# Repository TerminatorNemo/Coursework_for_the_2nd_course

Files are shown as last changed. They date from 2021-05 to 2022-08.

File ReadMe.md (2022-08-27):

# This is a folder with course work on analog electronics for the 2nd year

[Link to the video with the defense of the coursework](https://www.youtube.com/watch?v=7gKAiLStUtM&t=1s)

[Report for term paper](https://github.com/TerminatorNemo/Coursework_for_the_2nd_course/blob/main/Report%20for%20term%20paper.pdf)

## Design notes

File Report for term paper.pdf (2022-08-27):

НАЦІОНАЛЬНИЙ ТЕХНІЧНИЙ УНІВЕРСИТЕТ УКРАЇНИ «КИЇВСЬКИЙ ПОЛІТЕХНІЧНИЙ ІНСТИТУТ ІМЕНІ ІГОРЯ СІКОРСЬКОГО» Кафедра конструювання електронно-обчислювальної апаратури

КУРСОВА РОБОТА

з дисципліни ______Електронна компонентна база радіоелектронної апаратури______ на тему:___________ Підвищуючий DC-DC перетворювач на 555 таймері___________ __________________________________________________________________________

Студента 2 курсу групи ДК-92
Напряму підготовки: Телекоммунікації та радіотехніка
_______________Загреба А.Я._____________
(прізвище та ініціали)
Керівник:
________доцент, к.т.н. Короткий Є.В._______
(посада, вчене звання, науковий ступінь, прізвище та ініціали)
Національна оцінка: _____________________ Кількість балів: ______ Оцінка: ECTS ______
Члени комісії: _____________ | ___доцент, к.т.н. Короткий Є.В.___
(підпис) | (вчене звання, науковий ступінь, прізвище та ініціали)
_____________ | _________________________________
(підпис) | (вчене звання, науковий ступінь, прізвище та ініціали)

Київ - 2021 рік

ЗМІСТ

Розділ 2. Визначення характеристик, необхідних для вибору компонентів схеми ..... 9

ПЕРЕЛІК УМОВНИХ СКОРОЧЕНЬ

ШІМ-Широтно-імпульсна модуляція ЕРС- Електрорушійна сила
BOM- Bill Of Materials
УГО - Умовно графічне позначення КР – Курсова робота
NTC – Negative temperature coefficient DC – Direct current

ВСТУП

Темою КР було обрано підвищуючий DC-DC перетворювач на 555 таймері, який може перетворювати напругу 9 В у більш високу – 12 В. За основу була взята схема з сайту [1], але довелося замінити індуктивність та зворотний зв’язок, щоб на виході будо 12 В замість 19 В.

Метою цієї роботи є: аналіз та виправлення оригінальної схеми, замір струмів та напруг на компонентах, вибір компонентної бази, створення 3D моделі котушки індуктивності, створення бібліотеки та трасировка плати у Altium Designer.
В першому розділі буде проаналізовано роботу схеми та перероблено її на вхідну напругу 9 В та вихідну 12 В. Замість вхідної 12 В та вихідної 19 В.
В другому розділі буде виміряно напруги та струми на компонентах та занесено їх до таблиці.
В третьому розділі буде обрано потрібні компоненти.
В четвертому розділі буде розроблено 3D модель.
В п’ятому розділі буде розроблено бібліотеку для котушки та трасовано плату у Altium Designer.

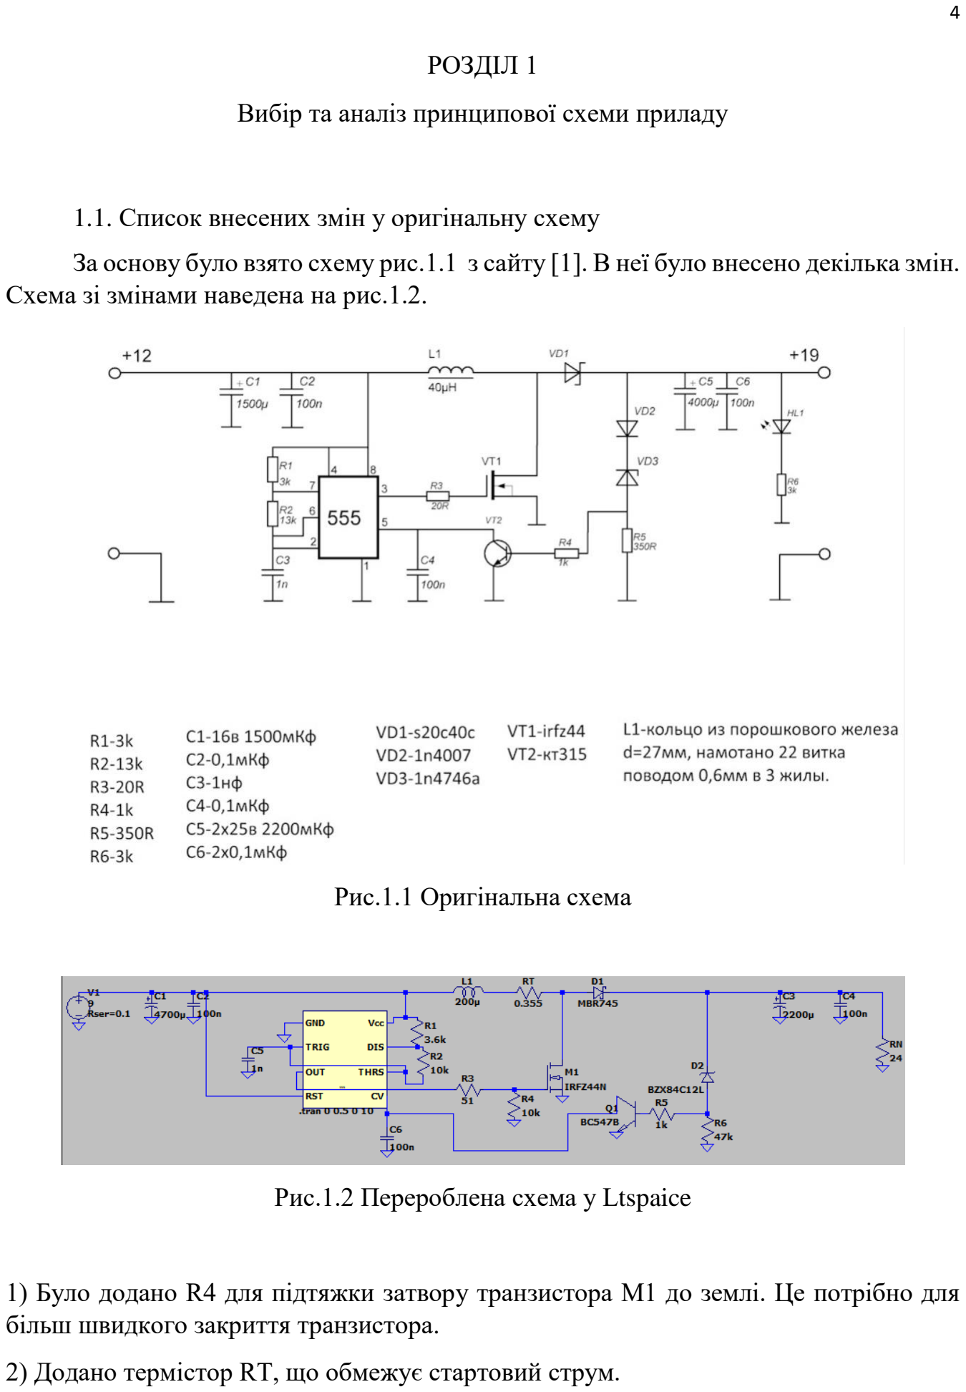
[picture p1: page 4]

РОЗДІЛ 1

Вибір та аналіз принципової схеми приладу

1.1. Список внесених змін у оригінальну схему

За основу було взято схему рис.1.1 з сайту [1]. В неї було внесено декілька змін. Схема зі змінами наведена на рис.1.2.

Рис.1.1 Оригінальна схема

Рис.1.2 Перероблена схема у Ltspaice

1) Було додано R4 для підтяжки затвору транзистора M1 до землі. Це потрібно для більш швидкого закриття транзистора.
2) Додано термістор RT, що обмежує стартовий струм.

3) Змінено зворотний зв’язок, щоб вихідна напруга була 12 В. Для цього було замінено стабілітрон на 12-вольтний та прибрано VD2, оскільки він став не потрібен (цей діод слугував для підвищення вихідної напруги на 0,7 В).
4) Резистори R1 та R2 були замінені на більш ходові. Через це частота ШІМ трохи змінилася, але це не критично (було 50 КГц, стало 63 КГц).
5) Опір резистора R3 було змінено, бо 555 таймер може видати 225 mA, напруга на третьому виводі сягає до 9 В, з резистором 20 Ом струм був би

9
20

= 0,45 А = 450 мА > 225 мА.

А з опором 51 Ом струм буде

9
51

= 0,18 А = 180 мА,

це 80% від максимального струму.

6) Було замінено діод VD1 (D1) на більш потужний аналог, бо не було можливості придбати той, що було використано в оригнальній схемі.
7) Було замінено конденсатори С1 та С3. Причиною заміни С1 стали великі пульсації на вході. С3 було замінено для більш швидкого виходу на робочий режим.
1.2. Аналіз роботи схеми
1.2.1. Вхідні конденсатори

Вхідні конденсатори С1 та С2 згладжують пульсації на вході схеми. А також дозволяють короткочасно отримувати великий струм. Короткочасний великий струм потрібен для пропускання великого струму через L1 при відкритому М1. Таким чином при закриванні М1 на котушці буде велика зміна струму за малий час. А це є умовою виникнення великого ЕРС самоіндукції.

Після чого 555 таймер генерує ШІМ сигнал з частотою 63 КГц на третьому виводі. Частота та скважність ШІМ задаються резисторами R1, R2 та конденсатором С5.

1.2.2. Генерація ШІМ таймером 555

Конденсатор С5 заряджається через резистори R1 та R2 (рис.1.2.2.1).

Поки напруга на С5 менше 1/3 напруги живлення на компараторі R (що підключений до інвертуючого контакту тригера) логічний сигнал 0, на виході компаратора S (що підключений до неінвертуючого контакту тригера) сигнал 1. Отже на інвертуючому виході тригера 0. В наслідок чого на виході схеми напруга живлення (бо після тригера стоїть інвертор).

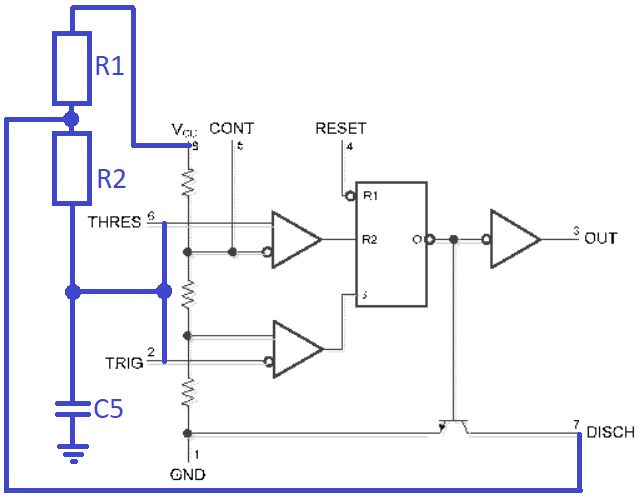
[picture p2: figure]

Рис.1.2.2.1 Схема 555 таймеру:

1) чорним представлена спрощена внутрішня схема 555 таймеру;
2) синім – його обв’язка у схемі.

Коли напруга на С5 більше 1/3 напруги живлення, але менше 2/3 напруги живлення, на виході обох компараторів 0, на виході тригера все ще 0. На виході схеми буде напруга живлення.

Коли напруга на С5 більше 2/3 напруги живлення, у компаратора R на виході 1, на виході компаратора S – 0, одже на виході тригера 1. Через це відкривається вбудований транзистор, конденсатор починає розряджатися через резистор R2. На виході схеми – 0 В.

Коли напруга на С5 більше 1/3 напруги живлення, але менше 2/3 напруги живлення, на виході обох компораторів 0, на виході тригера все ще 1. На виході схеми все ще 0 В.

Коли напруга на С5 стане менше 1/3 напруги живлення, на компараторі R логічний сигнал 0, а на виході компаратора S сигнал 1. Одже, на виході тригера 0. Транзистор закривається, цикл повторюється. На виході схеми напруга живлення.

Якщо вихід CONT (5 контакт) підтягнути до землі, опорна напруга компораторів зменшиться, скважність сигналу – зменшиться, частота – виросте.

1.2.3. Для чого потрібен ШІМ сигнал в цій схемі

ШІМ керує транзистором М1, коли транзистор відкрито – через індуктивність L1 тече струм.

В момент, коли транзистор закривається, на котушці індуктивності з’являється ЕРС самоіндукції, через різьке припинення протікання струму. (Чим більше зміна струму за менший час, тим більше ЕРС самоіндукції). ЕРС самоіндукції завжди направлено так, що воно протидіє зміні струму.

В нашому випадку, напрям ЕРС самоіндукції направлено вздовж стрілки (рис.1.2.2.2).

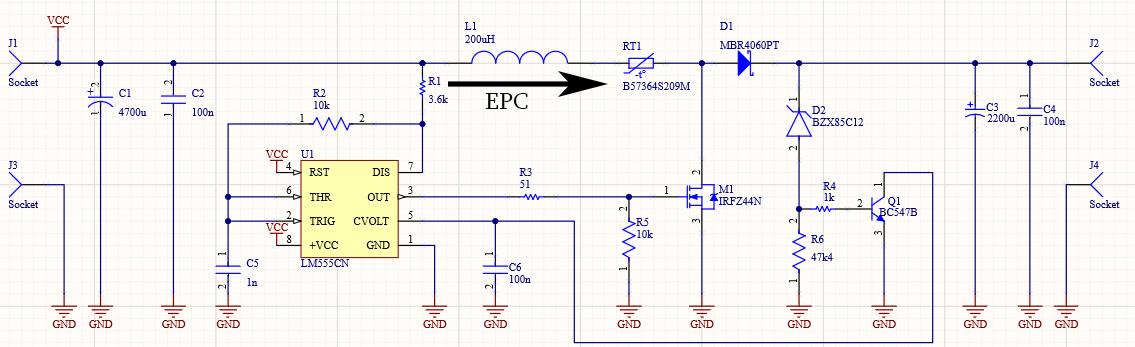
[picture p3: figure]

Рис.1.2.3.2 Схема з позначенням напрямку ЕРС.

Коли ЕРС перевищує напругу на вихідних конденсаторах на 0,7 В, діод D1 відкривається, вихідні конденсатори заряджаються.

1.2.4. Зворотний зв’язок

Якщо напруга на вихідних конденсаторах перевищує 12 В, стабілітрон D2 пробивається. Через нього починає текти струм, що відкривае транзистор Q1, який підтягує п’ятий вивід 555 таймеру до землі. Чим більший струм пропускає через себе стабілітрон, тим більше відкривається транзистор, тим сильніше він підтягує п’ятий вивід до землі, тим менше скважність ШІМ. Одже менше магнітної енергії накопичує котушка, через це менше ЕРС самоіндукції. Скважність може зменшуватись до повного відключення генерації, в такому випадку навантаження живиться від вихідних конденсаторів.

Коли напруга падає нижче 12 В, стабілітрон D2 закривається, транзистор Q1, закривається. В наслідок чого перестає підтягувати п’ятий вивід 555 таймеру до землі, таймер збільшує скважність ШІМ. І так по колу.

1.2.5. NTC термістор

NTC термістор потрібен, щоб при підключенні схеми вона не потребувала великого струму, з часом він розігрівається, його опір падає, і термістор майже не впливає на роботу схеми.

Термістор стоїть саме в цьому місті, оскільки, поки він не розігрівся, він визиває просадки напруги (оскільки обмежує струм). Якби він стояв до 555, могли б бути збої в роботі. А до чи після котушки – не суттєво, бо тут послідовне підключення.

1.3. Розрахунок котушки індуктивності

Тепер, оскільки було змінено вихідну та вхідну напруги, перерахуємо значення індуктивності котушки L1.

Uin=9В (напруга входу),

Uout=12В (напруга виходу),

Iout=0,5А (струм виходу),

f=63kГц=63 000Гц (частота ШІМ).

Lmin =

0.063∗Uout
Iout∗f

=

0.063∗12
0.5∗63000
= 0.000024Г=24mkГ. | (1.1)

Lmin =

0.25∗Uout
ImaxVT∗f

=

0.25∗12
48∗63000
= 0.000017Г=17mkГ. | (1.2)

Формули (1.1) і (1.2) було взято з [2], там це формули (10.16) і (10.17) відповідно.

Для надійної роботи краще взяти разів в 10 більше, отже візьмемо 200мкГ.

РОЗДІЛ 2

Визначення характеристик, необхідних для вибору компонентів схеми

Струми та напруги були виміряні у LTspaice. Виміри були проведені до розігріву термістора та після розігріву (замість термістора було використано резистор з еквівалентним опором). Всі значення було занесено у таблицю 2.1.

Потужність резисторів визначалася за формулою P=UI.

Таблиця 2.1

Струми та напруги на компонентах схеми

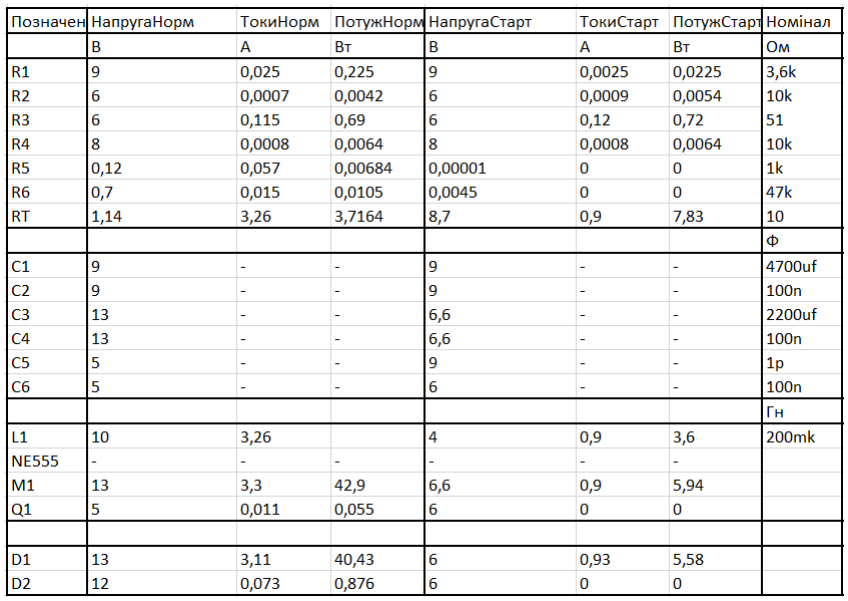
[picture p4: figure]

Норм – після розігріву термістора.

Старт – до розігріву термістора.

Посилання на схему, створену у Altium Designer [4]

РОЗДІЛ 3

Вибір елементної бази

В якості резистора R1 було обрано ERJ-P14J362U, оскільки його потужність 0,5 Вт, це більше за 0,24 Вт. (Якщо взяти резистор з потужністю 0,25 Вт, то буде замалий запас.) Номінал відповідає потрібному. Оскільки в схемі присутній зворотний зв’язок, то можна взяти резистор з невеликою точністю, отже 5% достатньо.
В якості резисторів R2, R5 (у LTspaice це R2 та R4) було вибрано RN73C2A10KBTG. Номінал відповідає потрібному. Потужність 0,1 Вт значно більше тої, що виділяється на цих резисторах.
Для R3 було вибрано ERJ-1TNF51R0U, номінал відповідає потрібному. Потужність в 1 Вт перевищує 0,72 Вт на 38,9%. При опорі 51 Ом, струм через нього становить 180 мА, це 80% від максимального струму 555 таймеру. Цей резистор має точність 1%, таким чином струм точно не перевищить 225 мА.
R4 (у LTspaice R5) це | RK73H2ATTE1001F, номінал відповідає, номінальна
потужність значно більше | розсіювальної. Формфактор 0805 дозволяє зібрати схему
вручну.

R6 – CRGP0805F47K. Номінал відповідає потрібному. Потужність більше розсіювальної.

C1 – MALREKA00FG447DG0K. Ємність відповідає потрібній. А напруга – був вибір або 16 В, або 9 В, оскільки напруга на ньому 9 В, то було вибрано 16 В, щоб був запас.

C2, C4, C6 - номінал відповідає, напруга 25 В, це більше 9 В та 12 В. Формфактор 0805, як було написано вище, менше брати не має сенсу.

C3 – 16ZLQ2200MEFC10X25. Номінал відповідає, напруга 16 В більше максимальної 13 В.

C5 – GMC21CG1R0C200NT, номінал відповідає, напруга значно більше максимальної, формфактор 0805. Точність – достатня.

RT1 – B57364S209M. Оскільки його задача обмежити стартовий струм, тут не потрібна велика точність, тому 20% точності достатньо. Він має пропускати не маленький струм (3,26 А), цей термістор розраховано на 12 А. Також можна використати його аналог, MF72-010D20, його максимальний струм 6 А, але цього все одно достатньо.

M1 – IRFZ44N, масксимальна розсіювальна потужність 110 Вт. Він в схемі не буде розсіюати більше 41 Вт, порогова напруга затвора 4 В, 555 таймер видає 9 В (у цій схемі).

Q1 – BC547B було використано в оригінальній схемі, але можна використати його аналог S9014.

U1 – LM555CN, оскільки використання приладу планується тільки у жилому приміщенні, то робоча температура 0–70 ˚С підходить. Напруга живлення 4–16 В, в схемі буде живитися від 9 В.

L1 – зроблена вручну. Діаметр дроту має бути не менше 0,66 мм. Індуктивність (як написано у розділі 1) 200 мкГн.

BOM експортований з Altium Designer (таблиця 3.1) [5].

Таблиця 3.1

BOM з Altium Designer

Comment | Description | Designator | Footprint | LibRef | Quantity
MALREKA00FG4 47DG0K | Cap Alum 4700UF 20% 16V Radial | C1 | FP-ECA-1HM102-MFG | MALREKA00FG 447DG0K | 1
C0805C104K3RA CAUTO | CAP CER 0.1UF 25V X7R 0805 | C2, C4, C6 | FP-C0805C-DN-IPC_A | CMP-2007-01164-2 | 3
16ZLQ2200MEFC 10X25 | Cap Aluminum Lytic 2200uF 16V 20% (10 X 25mm) Radial 5mm 2500mA 5000h 105C | C3 | PNSC-EEUFM1H221-2 | 16ZLQ2200MEF C10X25 | 1
GMC21CG1R0C2 00NT | CAP0805 COG 1PF .25PF 200V | C5 | FP-C0805C-DN-IPC_A | CMP-2007-00243-2 | 1
MBR4060PT | Schottky Diodes & Rectifiers 43 amp Rectifiers Schottky Barrier | D1 | FP-340BZ-MFG | MBR4060PT | 1
BZX85C12 | DIODE ZENER 12V 1W DO41 | D2 | FP-017AH-MFG | CMP-07164-000008-1 | 1

Продовж. табл. 3.1

Socket | Socket | J1, J2, J3, J4 | PIN1 | Socket | 4
IRFZ44N | MOSFET, Power; N-Ch; VDSS 55V; RDS(ON) 17.5 Milliohms; ID 49A; TO-220AB; PD 94W; -55deg | M1 | INF-PG-TO220-3-1 | IRFZ44N | 1
BC547B | Amplifier Transistor, NPN Silicon, 3-Pin TO-92, Bulk Box | Q1 | ONSC-TO-92-3-29-11 | CMP-1048-01467-1 | 1
ERJ-P14J362U | | R1 | RESC3225X70X 50ML20T20 | CMP-2005-03719-1 | 1
RN73C2A10KBT G | SMD Chip Resistor, Thin Film, 10KΩ, 100 V, 0805 [2012 Metric], 100 mW, 0.1%, RN73 Series | R2, R5 | FP-RN732A-IPC_A | CMP-03211-001029-1 | 2
51R 1% 2512(6432) | 51R 1W 1% 2512 (6432 Metric) SMD | R3 | RESC2512(6432) _M | CMP-1018-00364-1 | 1
RK73H2ATTE100 1F | | R4 | RESC2013X60X 30ML20T20 | CMP-2001-01881-1 | 1
CRGP0805F47K | CRGP0805 47KΩ 0.33W ±100ppm/°C 1% 150V | R6 | FP-CRGP0805-IPC_A | CMP-03211-006358-1 | 1
B57364S209M | Inrush Current Limiter, 2 Ohm, -55 to 170 degC, 2-Pin THD, RoHS, Bulk | RT1 | TDK-B57364 | CMP-2000-05907-1 | 1
LM555CN | Timer, 8-pin MDIP | U1 | N08E | CMP-0056-00017-2 | 1

РОЗДІЛ 4

Створення 3D моделі компоненту

1) Було накреслено 2 кола: зовнішнім діаметром 27 мм, внутрішнім діаметром 14 мм.
2) Потім було витягнуто їх у циліндр, з висотою 11 мм.
3) Зрізано края.
4) Накреслено 1 виток дроту, після чого за допомогою інструмента “pipe” було зроблено його 3D обєктом.
5) Після чого було зроблено 35 його копій навколо сердечника.
6) Ніжки було зроблено так само, як і перший виток дроту (рис. 4.1 – рис. 4.3).

Посилання на 3D модель [3]

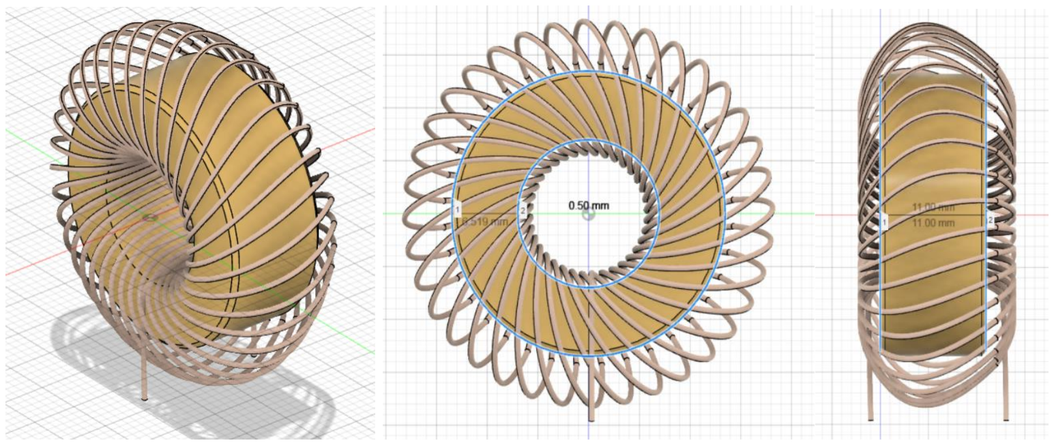
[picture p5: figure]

Рис.4.1 | Рис.4.2 | Рис.4.3

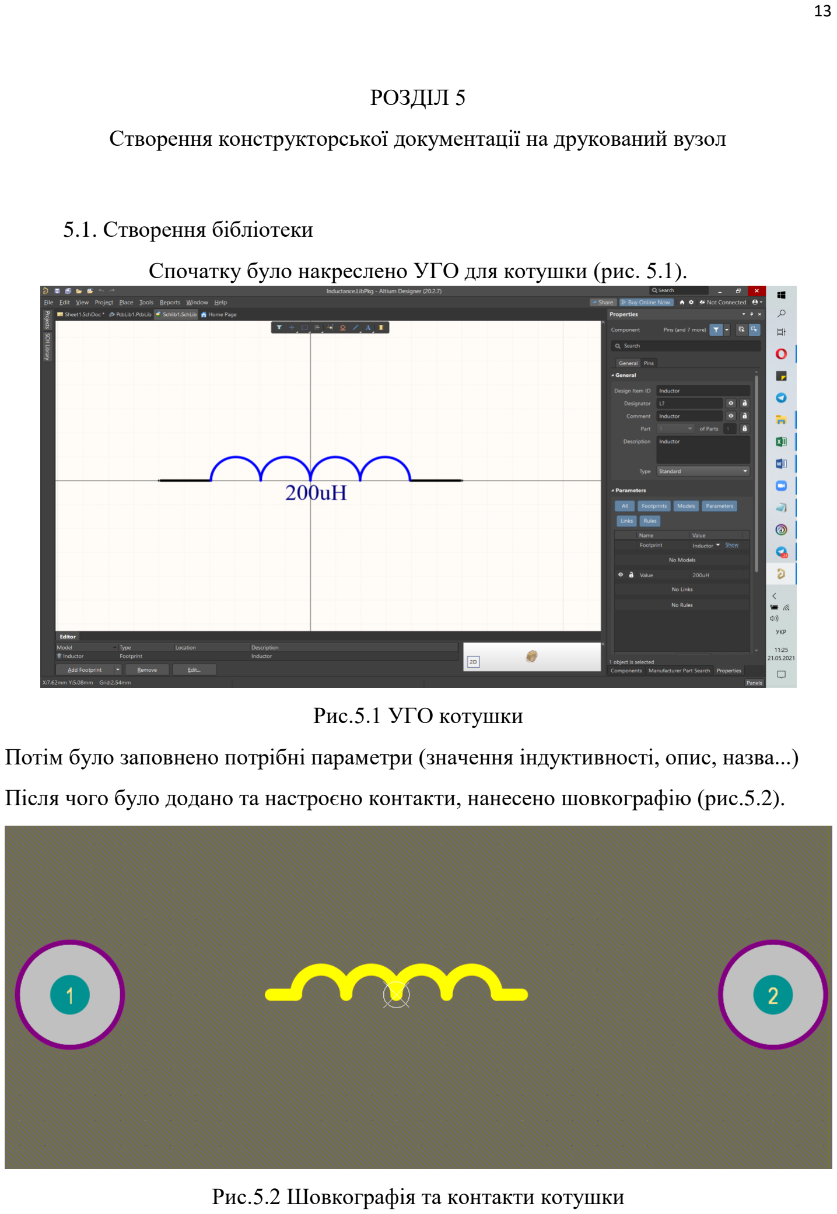
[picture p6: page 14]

РОЗДІЛ 5

Створення конструкторської документації на друкований вузол

5.1. Створення бібліотеки

Спочатку було накреслено УГО для котушки (рис. 5.1).

Рис.5.1 УГО котушки

Потім було заповнено потрібні параметри (значення індуктивності, опис, назва...)

Після чого було додано та настроєно контакти, нанесено шовкографію (рис.5.2).

Рис.5.2 Шовкографія та контакти котушки

Потім було додано створену в чертвертому розділі 3D модель (рис.5.3).

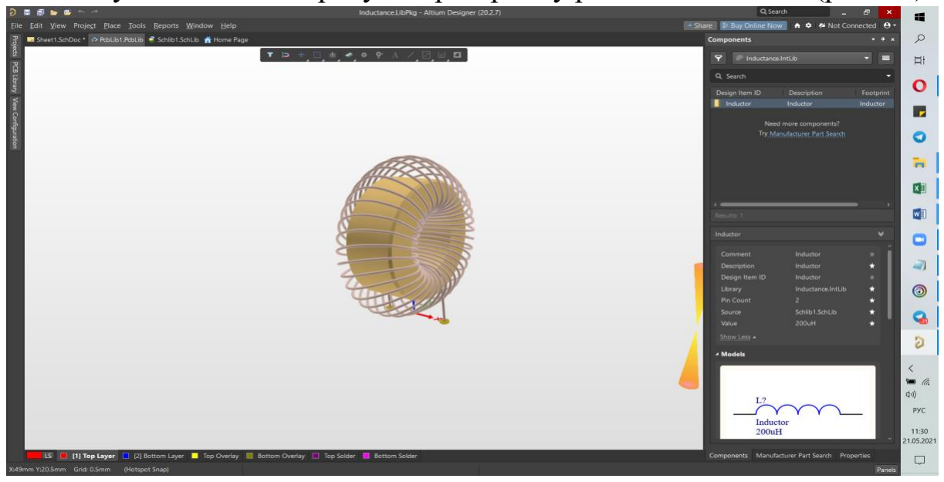
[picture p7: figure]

Рис.5.3 3D модель

5.2. Трасування схеми

Після завершення створення бібліотеки, вона була додана до проекту.

При створенні друкованої плати спочатку було нанесено усі компоненти на схему (рис.5.4). Для тих компонентів, у яких не було моделей, було додано елементи у тих самих корпусах, після чого використано “Add Supplier Link And Paremeters To Part”

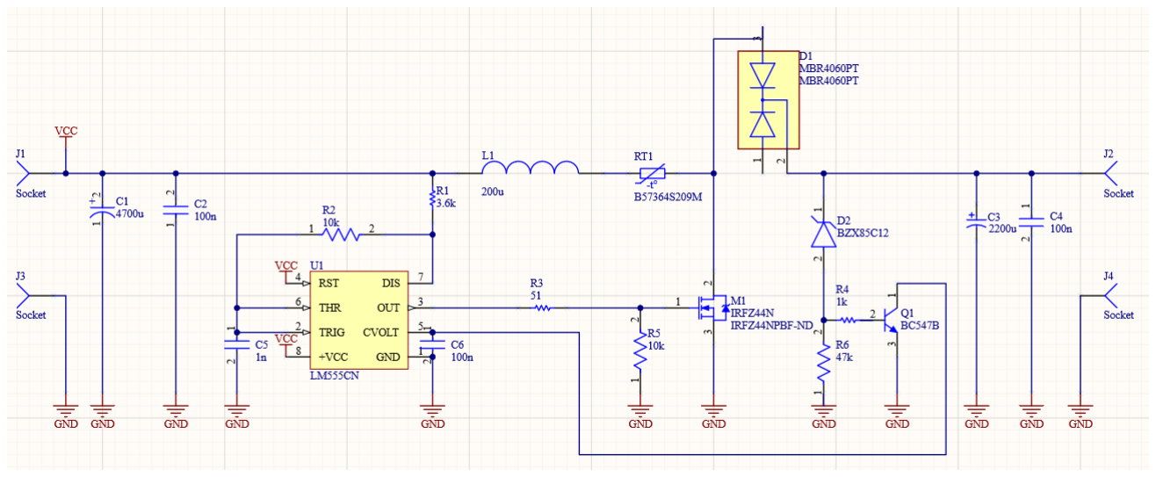
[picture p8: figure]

Рис.5.4 Схема створена у Altium Designer

Коли схема створена, вона була експортована у PsbDoc.

При трасировці схеми вдалося провести всі потрібні з’єднання на одній стороні, використавши лише одну перемичку. Результат наведено на рис. 5.5.

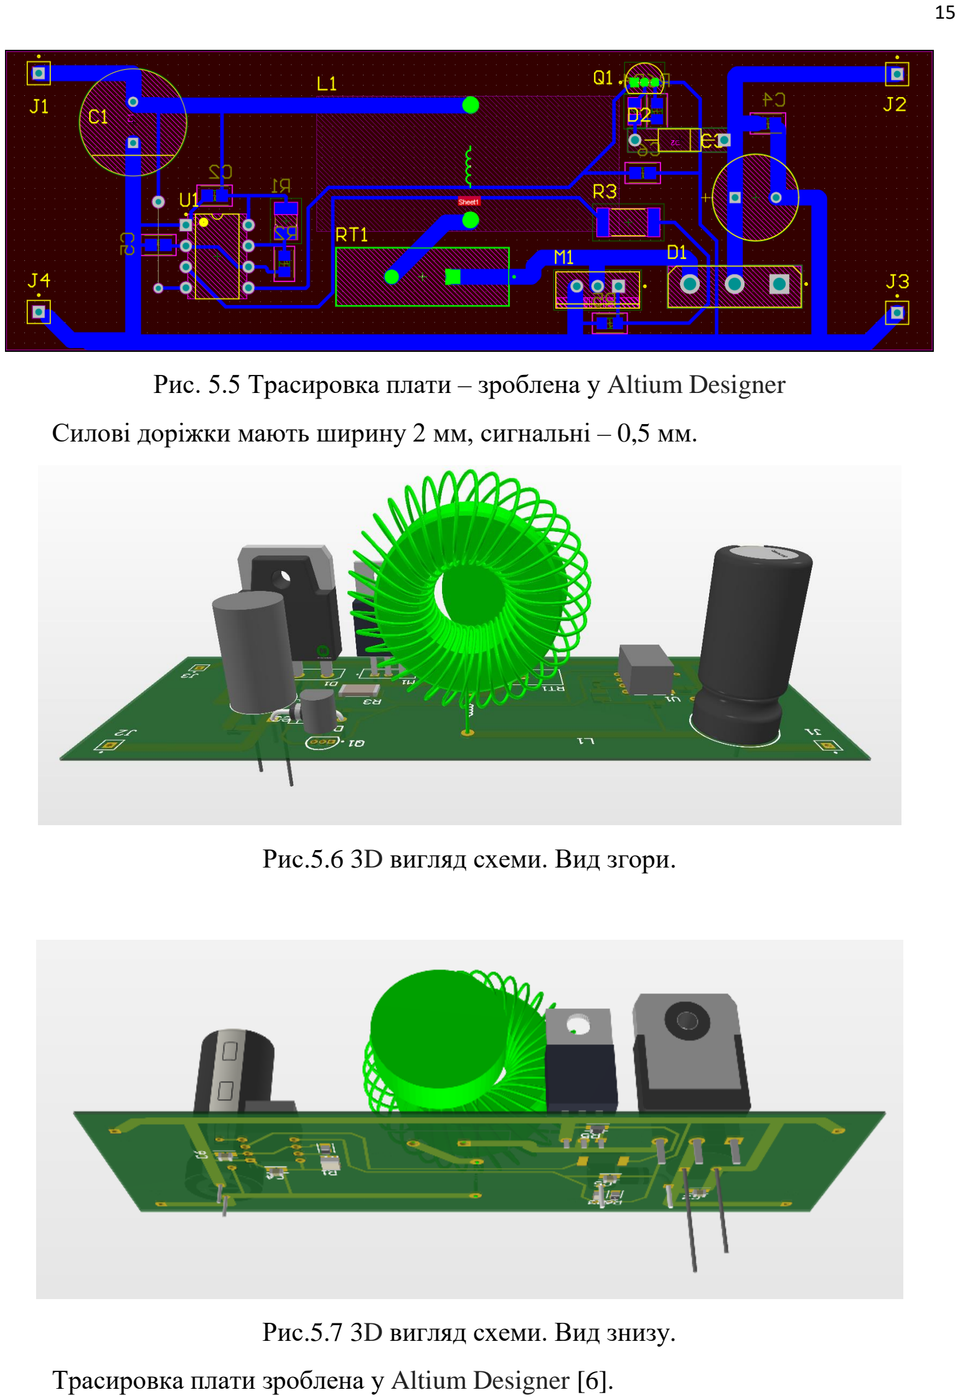
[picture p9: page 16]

Рис. 5.5 Трасировка плати – зроблена у Altium Designer

Силові доріжки мають ширину 2 мм, сигнальні – 0,5 мм.

Рис.5.6 3D вигляд схеми. Вид згори.

Рис.5.7 3D вигляд схеми. Вид знизу.

Трасировка плати зроблена у Altium Designer [6].

ВИСНОВОК

В першому розділі було проаналізовано роботу схеми та перероблено її на вхідну напругу 9 В, вихідну – 12 В. Замість вхідної 12 В, а вихідної – 19 В. Було замінено та перераховано котушку індуктивності, а також деякі резистори.
В другому розділі було виміряно напруги та струми на компонентах. Отримані значення були занесені до таблиці 2.1.
В третьому розділі було обрано потрібні компоненти.
В четвертому розділі було розроблено 3D модель.
В п’ятому розділі було зроблено бібліотеку для котушки та трасовано плату у Altium Designer.
При виконанні курсової роботи було використано Altium Designer [7], LTspice [8], Fusion 360 [9].

СПИСОК ВИКОРИСТАНИХ ДЖЕРЕЛ

1. Повишающий преобразователь напряжения на ne555 [Електронний ресурс] – Режим доступу до ресурсу: https://www.drive2.ru/c/469426869825962302.
2. Семенов. Б.Ю. Силовая электроника: от простого к сложному — М.: СОЛОН-Пресс, 2005. — 416 с.: ил. (Серия «Библиотека инженера»).
3. 3D модель котушки індуктивності [Електронний ресурс] – Режим доступу до ресурсу:
https://github.com/TerminatorNemo/kursova_2_kurs/blob/main/Kursova1%20v12.s tep. (https://github.com/TerminatorNemo/kursova_2_kurs/blob/main/Kursova1%20v12.step)
4. Схема створена у Altium Designer [Електронний ресурс] – Режим доступу до ресурсу:
https://github.com/TerminatorNemo/kursova_2_kurs/blob/main/Sheet1.SchDoc.
5. BOM експортований з Altium Designer у форматі .xlsx [Електронний ресурс] – Режим доступу до ресурсу:
https://github.com/TerminatorNemo/kursova_2_kurs/blob/main/Free%20Document s.xlsx. (https://github.com/TerminatorNemo/kursova_2_kurs/blob/main/Free%20Documents.xlsx)
6. Друкована плата створена у Altium Designer у форматі [Електронний ресурс] – Режим доступу до ресурсу:
https://github.com/TerminatorNemo/kursova_2_kurs/blob/main/PCB1.PcbDoc.
7. Altium Designer [Програма] – Посилання на скачування: https://www.altium.com/ru.
8. LTspice [Програма] – Посилання на скачування: https://www.analog.com/ru/design-center/design-tools-and-calculators/ltspicesimulator.html. (https://www.analog.com/ru/design-center/design-tools-and-calculators/ltspice-simulator.html)
9. Fusion 360 [Програма] – Посилання на скачування: https://www.autodesk.com/products/fusion-360.

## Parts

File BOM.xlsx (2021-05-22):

Comment | Description | Designator | Footprint | LibRef | Quantity
MALREKA00FG447DG0K | Cap Alum 4700UF 20% 16V Radial | C1 | FP-ECA-1HM102-MFG | MALREKA00FG447DG0K | 1
C0805C104K3RACAUTO | CAP CER 0.1UF 25V X7R 0805 | C2, C4, C6 | FP-C0805C-DN-IPC_A | CMP-2007-01164-2 | 3
16ZLQ2200MEFC10X25 | Cap Aluminum Lytic 2200uF 16V 20% (10 X 25mm) Radial 5mm 2500mA 5000h 105C | C3 | PNSC-EEUFM1H221-2 | 16ZLQ2200MEFC10X25 | 1
GMC21CG1R0C200NT | 1 pF ±0.25pF 200V Ceramic Capacitor C0G, NP0 0805R 0805 | C5 | FP-C0805C-DN-IPC_A | CMP-2007-00243-2 | 1
MBR4060PT | Schottky Diodes & Rectifiers 43 amp Rectifiers Schottky Barrier | D1 | FP-340BZ-MFG | MBR4060PT | 1
BZX85C12 | DIODE ZENER 12V 1W DO41 | D2 | FP-017AH-MFG | CMP-07164-000008-1 | 1
Socket | Socket | J1, J2, J3, J4 | PIN1 | Socket | 4
Inductor | Inductor | L1 | Inductor | Inductor | 1
IRFZ44N | MOSFET, Power; N-Ch; VDSS 55V; RDS(ON) 17.5 Milliohms; ID 49A; TO-220AB; PD 94W; -55deg | M1 | INF-PG-TO220-3-1 | IRFZ44N | 1
BC547B | Amplifier Transistor, NPN Silicon, 3-Pin TO-92, Bulk Box | Q1 | ONSC-TO-92-3-29-11 | CMP-1048-01467-1 | 1
ERJ-P14J362U |  | R1 | RESC3225X70X50ML20T20 | CMP-2005-03719-1 | 1
RN73C2A10KBTG | SMD Chip Resistor, Thin Film, 10KΩ, 100 V, 0805 [2012 Metric], 100 mW, 0.1%, RN73 Series | R2, R5 | FP-RN732A-IPC_A | CMP-03211-001029-1 | 2
51R 1% 2512(6432) | 51R 1W 1% 2512 (6432 Metric) SMD | R3 | RESC2512(6432)_M | CMP-1018-00364-1 | 1
RK73H2ATTE1001F |  | R4 | RESC2013X60X30ML20T20 | CMP-2001-01881-1 | 1
CRGP0805F47K | CRGP0805 47KΩ 0.33W ±100ppm/°C 1% 150V | R6 | FP-CRGP0805-IPC_A | CMP-03211-006358-1 | 1
B57364S209M | Inrush Current Limiter, 2 Ohm, -55 to 170 degC, 2-Pin THD, RoHS, Bulk | RT1 | TDK-B57364 | CMP-2000-05907-1 | 1
LM555CN | Timer, 8-pin MDIP | U1 | N08E | CMP-0056-00017-2 | 1

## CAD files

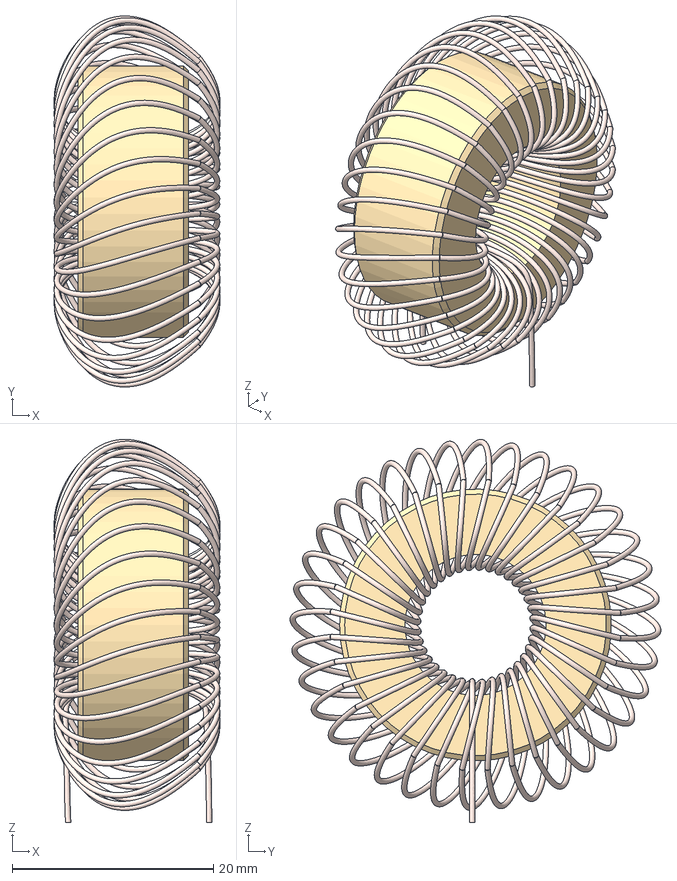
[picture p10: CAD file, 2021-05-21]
Kursova1 v12.step
16.5 x 36.9 x 38.1 mm
